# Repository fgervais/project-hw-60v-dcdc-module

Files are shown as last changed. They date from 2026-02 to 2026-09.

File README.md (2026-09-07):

# 4.3V to 60V input / 0.8V to 30V output switching converter

- [PCB v1.0.0-5-g07f53f4](#pcb-v100-5-g07f53f4)
  - [Switching converter analysis](#switching-converter-analysis)
    - [Switch node](#switch-node)
  - [Output (5V, 2x 10uF 50V output capacitors)](#output-5v-2x-10uf-50v-output-capacitors)
  - [Output (5V, 2x 22uF 16V output capacitors)](#output-5V-2x-22uF-16V-output-capacitors)
- [PCB v1.0.0-5-g07f53f4 (hack1)](#pcb-v100-5-g07f53f4-hack1)
  - [Switching converter analysis](#switching-converter-analysis-lmr51625)
  - [Output (5V, 2x 22uF 16V output capacitors)](#output-5V-lmr51625-2x-22uF-16V-output-capacitors)
- [PCB v2.0.0](#pcb-v200)
  - [Switching converter analysis](#switching-converter-analysis-v200)
  - [Output (5V, Snubber 5.1Ω/100pF)](#output-5v-v200-snubber-51ω100pf)
  - [Output (5V, Snubber 5.1Ω/100pF, 3.3uF)](#output-5v-v200-snubber-51ω100pf-33uf)

## PCB v1.0.0-5-g07f53f4

### Switching converter analysis

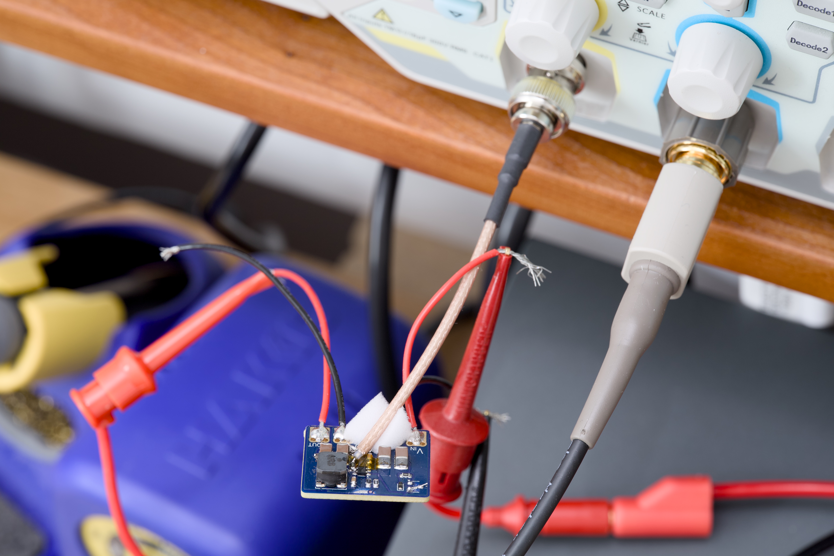
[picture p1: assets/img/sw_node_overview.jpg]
Overview


50 ohms series termination at the SW node.

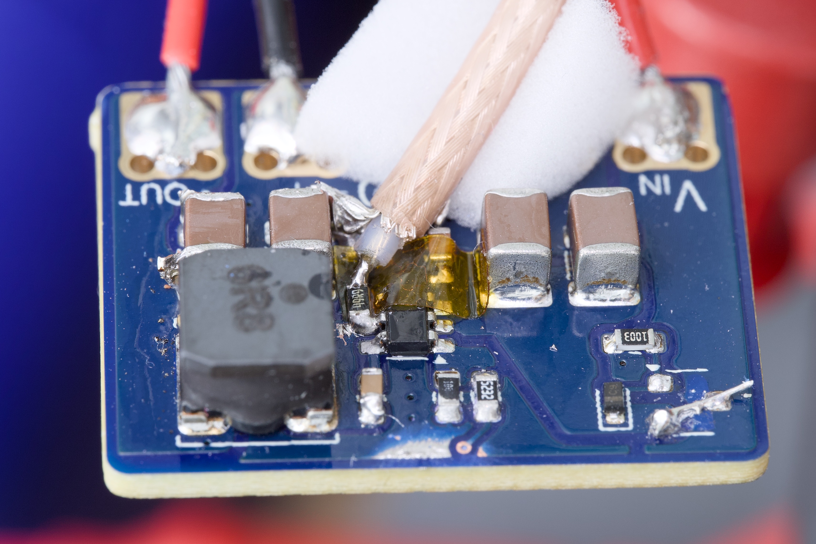
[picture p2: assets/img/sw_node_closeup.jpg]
Closeup


#### Switch node

| Input Voltage | Waveform | Rising edge |
|---|---|---|
| 10V | Waveform | Rising |
| 20V | Waveform | Rising |
| 48V | Waveform | Rising |

### Output (5V, 2x 10uF 50V output capacitors)

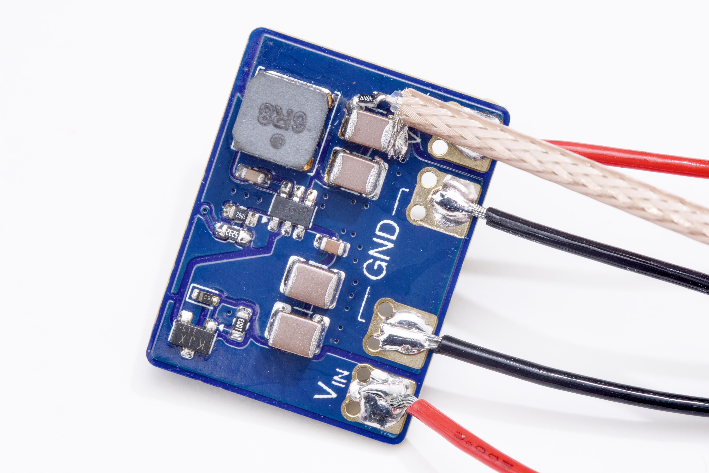
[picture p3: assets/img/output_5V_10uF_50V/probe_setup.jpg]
Probe Setup


| Input Voltage | No Load | 50 mA | 500 mA | 1 A |
|---|---|---|---|-----|
| 10V | Waveform | Waveform | Waveform | Waveform |
| 20V | Waveform | Waveform | Waveform | Waveform |
| 48V | Waveform | Waveform | Waveform | Waveform |

| Input Voltage | No Load | 50 mA | 500 mA | 1 A |
|---|---|---|---|-----|
| 10V | Waveform | Waveform | Waveform | Waveform |
| 20V | Waveform | Waveform | Waveform | Waveform |
| 48V | Waveform | Waveform | Waveform | Waveform |

#### Noise

| Input Voltage | No Load | 50 mA | 500 mA | 1 A |
|---|---|---|---|-----|
| 10V | 73.60 mV (1.47%) | 73.60 mV (1.47%) | 20.80 mV (0.42%) | 19.20 mV (0.38%) |
| 20V | 49.20 mV (0.98%) | 49.20 mV (0.98%) | 26.00 mV (0.52%) | 27.20 mV (0.54%) |
| 48V | 49.20 mV (0.98%) | 49.20 mV (0.98%) | 45.20 mV (0.90%) | 40.40 mV (0.81%) |

### Output (5V, 2x 22uF 16V output capacitors)

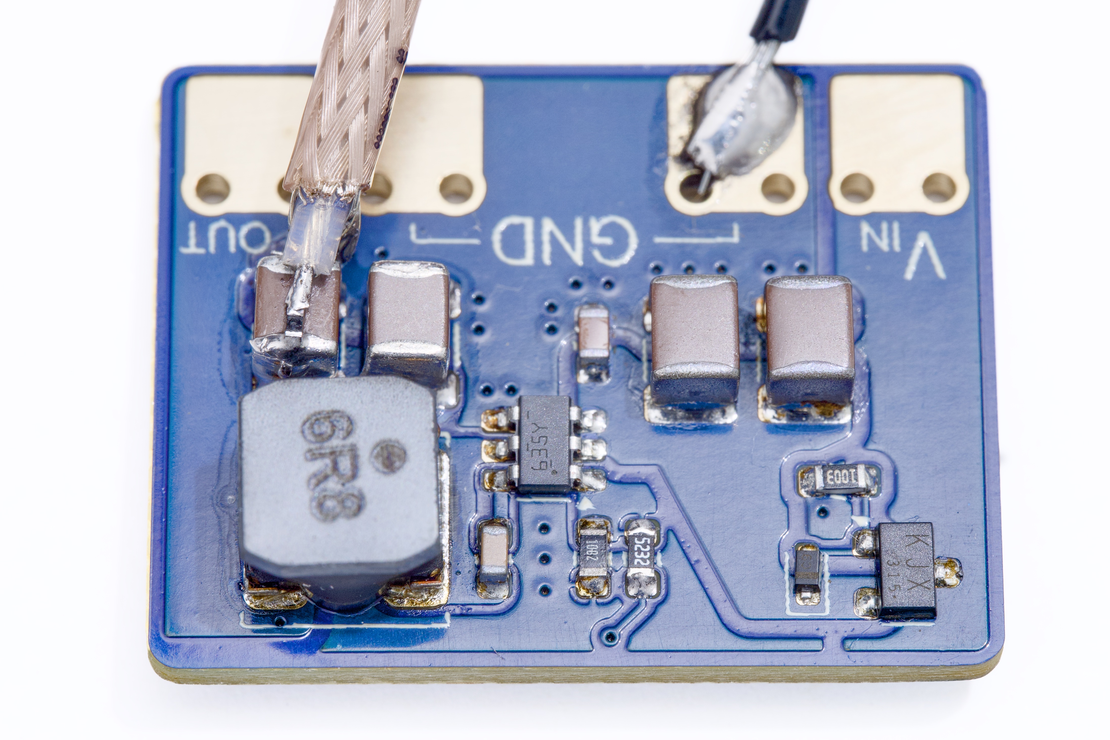
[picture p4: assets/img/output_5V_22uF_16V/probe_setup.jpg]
Probe Setup


| Input Voltage | No Load | 50 mA | 500 mA | 1 A |
|---|---|---|---|-----|
| 10V | Waveform | Waveform | Waveform | Waveform |
| 20V | Waveform | Waveform | Waveform | Waveform |
| 48V | Waveform | Waveform | Waveform | Waveform |

| Input Voltage | No Load | 50 mA | 500 mA | 1 A |
|---|---|---|---|-----|
| 10V | Waveform | Waveform | Waveform | Waveform |
| 20V | Waveform | Waveform | Waveform | Waveform |
| 48V | Waveform | Waveform | Waveform | Waveform |

#### Noise

| Input Voltage | No Load | 50 mA | 500 mA | 1 A |
|---|---|---|---|-----|
| 10V | 31.40 mV (0.63%) | 32.40 mV (0.65%) | 16.40 mV (0.33%) | 15.20 mV (0.30%) |
| 20V | 22.80 mV (0.46%) | 24.40 mV (0.49%) | 19.60 mV (0.39%) | 19.20 mV (0.38%) |
| 48V | 23.60 mV (0.47%) | 26.20 mV (0.52%) | 21.00 mV (0.42%) | 21.20 mV (0.42%) |

### Output (24V, 2x 10uF 50V output capacitors)

| Input Voltage | No Load | 50 mA | 500 mA | 1 A |
|---|---|---|---|-----|
| 10V | Waveform | Waveform | Waveform | Waveform |
| 20V | Waveform | Waveform | Waveform | Waveform |
| 48V | Waveform | Waveform | Waveform | Waveform |

| Input Voltage | No Load | 50 mA | 500 mA | 1 A |
|---|---|---|---|-----|
| 10V | Waveform | Waveform | Waveform | Waveform |
| 20V | Waveform | Waveform | Waveform | Waveform |
| 48V | Waveform | Waveform | Waveform | Waveform |

#### Noise

| Input Voltage | No Load | 50 mA | 500 mA | 1 A |
|---|---|---|---|-----|
| 10V |  mV (%) |  mV (%) |  mV (%) |  mV (%) |
| 20V |  mV (%) |  mV (%) |  mV (%) |  mV (%) |
| 48V |  mV (%) |  mV (%) |  mV (%) |  mV (%) |

## PCB v1.0.0-5-g07f53f4 (hack1)

### Switching converter analysis (LMR51625)

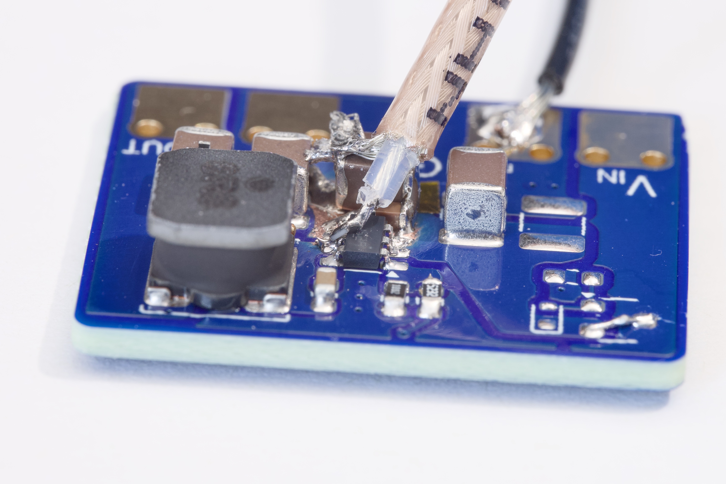
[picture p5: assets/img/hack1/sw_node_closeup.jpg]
Closeup


#### Switch node

| Input Voltage | Waveform | Rising edge |
|---|---|---|
| 10V | Waveform | Rising |
| 20V | Waveform | Rising |
| 48V | Waveform | Rising |

### Output (5V, LMR51625, 2x 22uF 16V output capacitors)

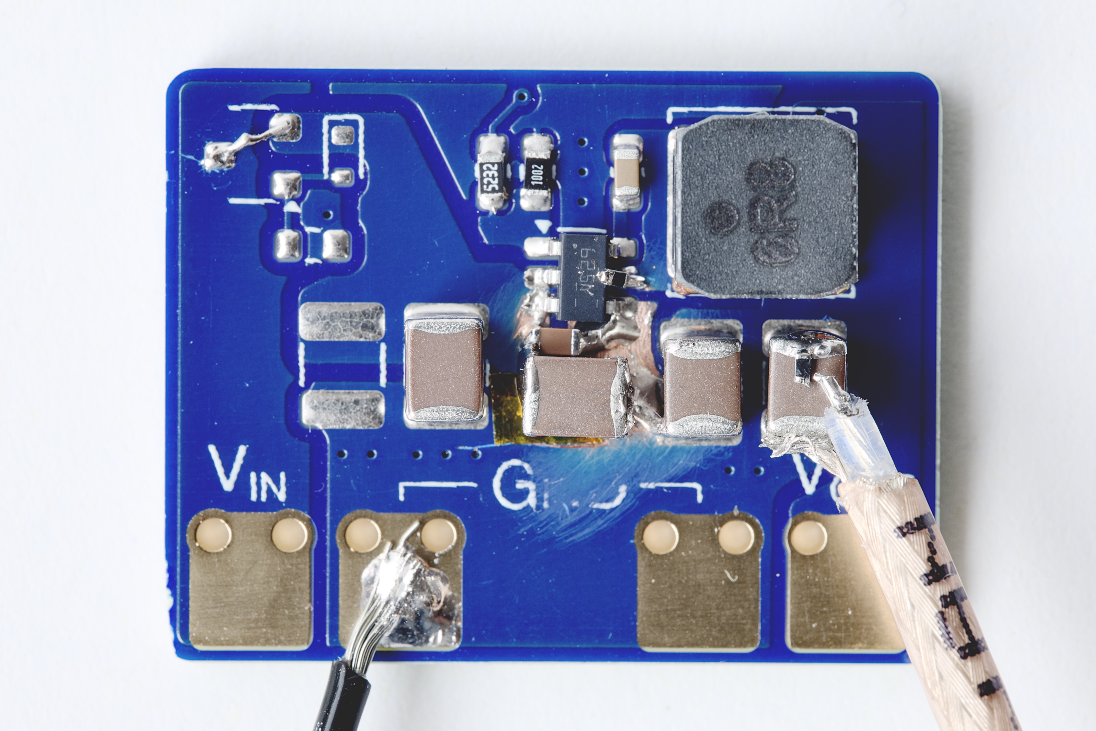
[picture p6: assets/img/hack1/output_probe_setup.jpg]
Probe Setup


| Input Voltage | No Load | 50 mA | 500 mA | 1 A |
|---|---|---|---|-----|
| 10V | Waveform | Waveform | Waveform | Waveform |
| 20V | Waveform | Waveform | Waveform | Waveform |
| 48V | Waveform | Waveform | Waveform | Waveform |

| Input Voltage | No Load | 50 mA | 500 mA | 1 A |
|---|---|---|---|-----|
| 10V | Waveform | Waveform | Waveform | Waveform |
| 20V | Waveform | Waveform | Waveform | Waveform |
| 48V | Waveform | Waveform | Waveform | Waveform |

#### Noise

| Input Voltage | No Load | 50 mA | 500 mA | 1 A |
|---|---|---|---|-----|
| 10V | 18.80 mV (0.37%) | 20.00 mV (0.40%) | 11.80 mV (0.24%) | 12.00 mV (0.24%) |
| 20V | 13.80 mV (0.28%) | 15.40 mV (0.31%) | 15.40 mV (0.31%) | 15.20 mV (0.30%) |
| 48V | 15.40 mV (0.31%) | 17.40 mV (0.35%) | 35.60 mV (0.71%) | 19.00 mV (0.38%) |

## PCB v2.0.0

### Switching converter analysis v2.0.0

Closeup

#### Switch node

| Input Voltage | Waveform | Rising edge |
|---|---|---|
| 10V | Waveform | Rising |
| 20V | Waveform | Rising |
| 48V | Waveform | Rising |

Frequency

#### Switch node (Snubber 5.1Ω/100pF)

Closeup

| Input Voltage | Rising edge |
|---|---|
| 10V | Waveform |
| 20V | Waveform |
| 48V | Waveform |

### Output (5V, v2.0.0, Snubber 5.1Ω/100pF)

Probe Setup

| Input Voltage | No Load | 50 mA | 500 mA | 1 A |
|---|---|---|---|-----|
| 10V | Waveform | Waveform | Waveform | Waveform |
| 20V | Waveform | Waveform | Waveform | Waveform |
| 48V | Waveform | Waveform | Waveform | Waveform |

| Input Voltage | No Load | 50 mA | 500 mA | 1 A |
|---|---|---|---|-----|
| 10V | Waveform | Waveform | Waveform | Waveform |
| 20V | Waveform | Waveform | Waveform | Waveform |
| 48V | Waveform | Waveform | Waveform | Waveform |

### Output (5V, v2.0.0, Snubber 5.1Ω/100pF, 3.3uF)

| Input Voltage | No Load | 50 mA | 500 mA | 1 A |
|---|---|---|---|-----|
| 10V | Waveform | Waveform | Waveform | Waveform |
| 20V | Waveform | Waveform | Waveform | Waveform |
| 48V | Waveform | Waveform | Waveform | Waveform |

| Input Voltage | No Load | 50 mA | 500 mA | 1 A |
|---|---|---|---|-----|
| 10V | Waveform | Waveform | Waveform | Waveform |

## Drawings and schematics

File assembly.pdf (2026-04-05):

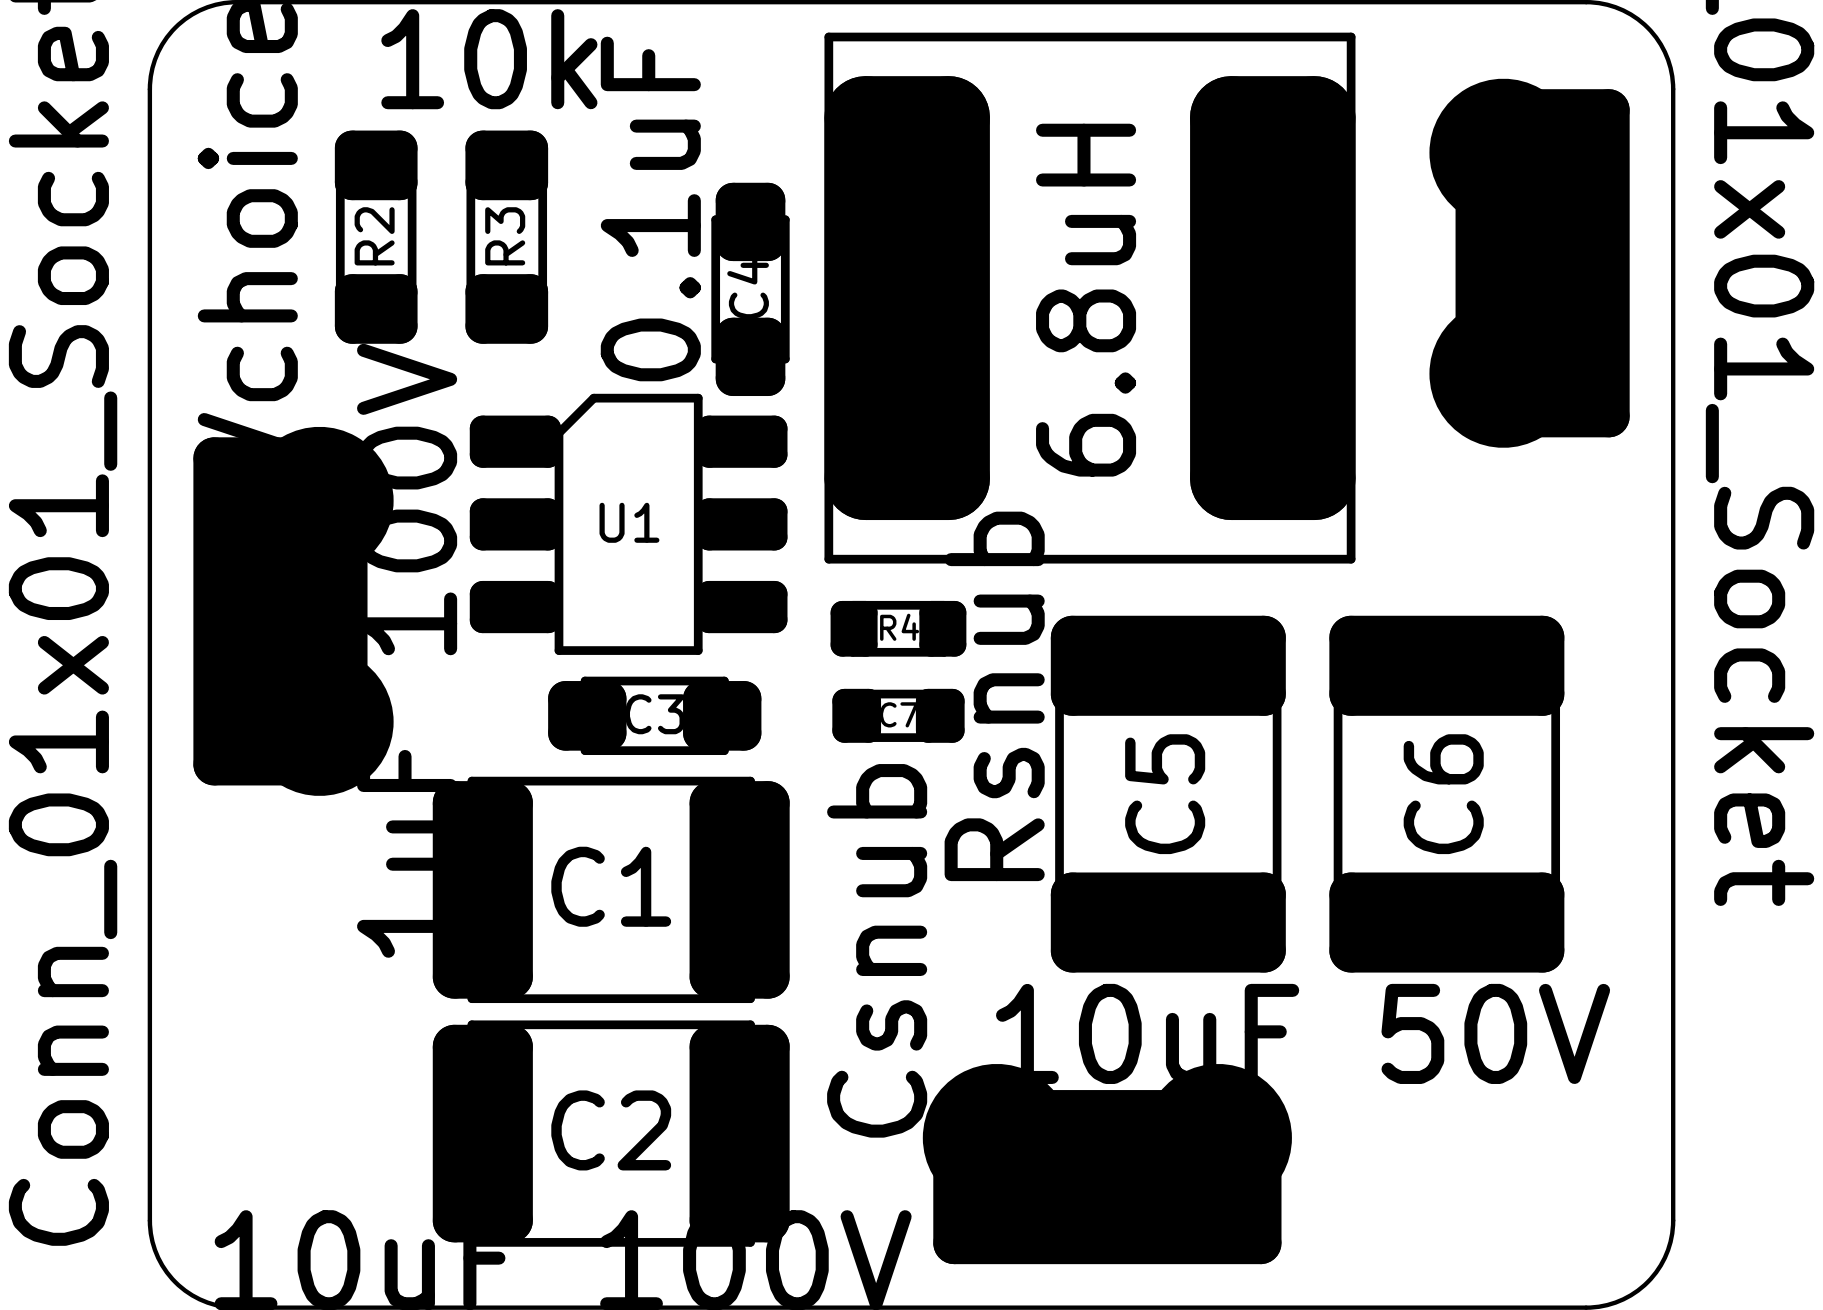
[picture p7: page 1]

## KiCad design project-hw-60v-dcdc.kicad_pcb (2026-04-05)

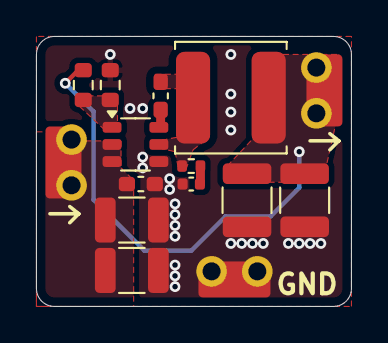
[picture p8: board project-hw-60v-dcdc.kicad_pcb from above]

Board: 4 copper layers, 17.5 x 15.0 mm, 15 parts (0 on the bottom side), 7 nets.

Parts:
C1, C2: 10uF 100V; C_1210_3225Metric_Tight
C3: 1uF 100V; C_0603_1608Metric_Tight
C4: 0.1uF; C_0603_1608Metric_Tight
C5, C6: 10uF 50V; C_1210_3225Metric
C7: Csnub; C_0402_1005Metric
J1, J2, J3: Conn_01x01_Socket; EdgePad_1x1_Short
L1: 6.8uH; L_TDK_VLS6045EX_VLS6045AF
R2: Vchoice; R_0603_1608Metric
R3: 10k; R_0603_1608Metric
R4: Rsnub; R_0402_1005Metric
U1: LMR516x5; TSOT-23-6_Tight

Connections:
/LMR516x5 Converter/FB: R2.2, R3.1, U1.1 (FB)
/LMR516x5 Converter/Vin: C1.1, C2.1, C3.1, J1.1, U1.2 (EN), U1.3 (VIN)
/LMR516x5 Converter/Vout: C5.1, C6.1, J3.1, L1.2, R2.1
GND: C1.2, C2.2, C3.2, C5.2, C6.2, C7.2, J2.1, R3.2, U1.4 (GND)
unnamed: C7.1, R4.2
unnamed: C4.1, U1.6 (CB)
unnamed: C4.2, L1.1, R4.1, U1.5 (SW)

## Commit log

2026-01-02 sch: add 2 blocks
    [lmr516x5_converter.kicad_sch, project-hw-60v-dcdc.kicad_pcb, project-hw-60v-dcdc.kicad_sch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]
2026-01-02 sch: first draft
    [lmr516x5_converter.kicad_sch, project-hw-60v-dcdc.kicad_sch, reverse_polarity_protection.kicad_sch]
2026-01-03 pcb: first placement
    [project-hw-60v-dcdc.kicad_pcb]
2026-01-03 pcb: first routing no errors
    [project-hw-60v-dcdc.kicad_pcb]
2026-01-03 pcb: add ground vias
    [project-hw-60v-dcdc.kicad_pcb]
2026-01-03 pcb: set board edge closer to golden pads
    [project-hw-60v-dcdc.kicad_pcb]
2026-01-03 pcb: add version
    [project-hw-60v-dcdc.kicad_pcb]
2026-01-03 pcb: change tolerances to 0.25 mm
    [project-hw-60v-dcdc.kicad_pcb]
2026-01-03 pcb: update pcb version
    [project-hw-60v-dcdc.kicad_pcb]
2026-01-03 Close kicad
2026-01-04 pcb: make board 1 mm larger on the right
    [project-hw-60v-dcdc.kicad_pcb]
2026-01-04 pcb: update version
    [project-hw-60v-dcdc.kicad_pcb]
2026-01-04 Add gerbers
    [project-hw-60v-dcdc-B_Cu.gbr, project-hw-60v-dcdc-B_Mask.gbr, project-hw-60v-dcdc-B_Paste.gbr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]
2026-01-08 Change entry 0.1uF cap to 1uF 100V
    [lmr516x5_converter.kicad_sch]
2026-01-08 Add assembly file
    [project-hw-60v-dcdc.kicad_pcb]
2026-02-10 Add switch node analysis to README
2026-03-09 First placement
    [lmr516x5_converter.kicad_sch, project-hw-60v-dcdc.kicad_pcb, project-hw-60v-dcdc.kicad_sch]
2026-03-10 First routing
    [lmr516x5_converter.kicad_sch, project-hw-60v-dcdc.kicad_pcb, project-hw-60v-dcdc.kicad_sch]
2026-03-11 Add inner ground planes
    [project-hw-60v-dcdc.kicad_pcb]
2026-03-11 Pass DRC
    [project-hw-60v-dcdc.kicad_pcb]
2026-03-11 Add copper pour under the inductor
    [project-hw-60v-dcdc.kicad_pcb]
2026-03-12 Change ground silkscreen
    [project-hw-60v-dcdc.kicad_pcb]
2026-03-12 README: add v1 5V probe setup
2026-03-16 README: add output probe setup image
2026-03-21 Resize copper
    [project-hw-60v-dcdc.kicad_pcb]
2026-03-21 pcb: update silkscreen version
    [project-hw-60v-dcdc.kicad_pcb]
2026-03-21 Update gerbers
    [project-hw-60v-dcdc-B_Cu.gbr, project-hw-60v-dcdc-B_Mask.gbr, project-hw-60v-dcdc-B_Paste.gbr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]
2026-04-05 Update assembly file
    [project-hw-60v-dcdc.kicad_pcb]
2026-04-19 README: add v2.0.0 switch node
2026-04-20 README: add switch node image
2026-04-29 RAEDME: add output for Snubber 5.1Ω/100pF
2026-04-29 README: add snubber 5.1Ω/100pF output noise
2026-04-29 README: add output probe setup
